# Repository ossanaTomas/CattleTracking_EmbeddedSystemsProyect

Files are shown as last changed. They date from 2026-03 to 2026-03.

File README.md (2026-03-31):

# Cattle Tracking System — Embedded Systems Project

## Table of Contents

- [Motivation](#motivation)
- [Overview](#overview)
- [Key Features](#key-features)
- [Repository Structure](#repository-structure)
- [Hardware Design](#hardware-design)
  - [Tracker Board (Collar Node)](#tracker-board-collar-node)
  - [Base Station Board](#base-station-board)
- [Firmware](#firmware)
  - [Tracker Firmware](#tracker-firmware-firmwarefirmware-tracker)
  - [Base Station Firmware](#base-station-firmware-firmwarefirmware-base-station)
- [Communication Protocol](#communication-protocol)
- [Dashboard Application](#dashboard-application-dashboard-app)
- [Technology Stack Summary](#technology-stack-summary)
- [Academic Context](#academic-context)
- [Author](#author)

---

## Motivation

My father is a farmer. Every single day he drives out to the field to walk the land, check on the animals, make sure they are healthy and in the right paddock. It is a time-consuming routine that depends entirely on being physically present.

That got me thinking: what if I could apply my knowledge as an engineering student to make his daily work easier? With a satellite tracking system he could simply pull out his phone, check an app, and know the status of every animal in real time — without leaving the house.

That question became this project. For the *Programación de Sistemas Embebidos* course I decided to build a **low-power, long-range embedded solution** that tackles exactly that problem. The result is a working prototype: custom PCBs, bare-metal firmware, a LoRa radio link, and a web dashboard, all built from scratch.

The system is still a prototype and has room to grow in several areas, but it is **fully functional** — and with a reasonable amount of additional development it could be deployed in a real field environment without any fundamental obstacles.

---

## Overview

An end-to-end **IoT solution for GPS-based livestock tracking** built entirely from scratch — custom PCBs, embedded firmware, and a web dashboard included.

The goal was to design a **low-power, long-range** monitoring system that can be attached to cattle collars. Each collar (tracker node) periodically collects GPS coordinates and body temperature, and transmits this data wirelessly to a fixed base station using **LoRa radio modules**. The base station forwards all received data to a PC, where a web application stores and visualizes it in real time.

```
┌─────────────────────────────────────────────────────────────────┐
│                         FIELD                                   │
│                                                                 │
│  ┌──────────────┐       LoRa        ┌──────────────────────┐   │
│  │   Tracker    │ ────────────────► │    Base Station      │   │
│  │  (Collar)    │ ◄──────── ACK/CFG │  (Fixed / Fencepost) │   │
│  │              │                   │                      │   │
│  │ STM32F103    │                   │ STM32F103            │   │
│  │ GPS (u-blox) │                   │ USB CDC              │   │
│  │ DS18B20 Temp │                   └──────────┬───────────┘   │
│  │ SX127x LoRa  │                              │               │
│  └──────────────┘                              │ USB Serial    │
│                                                │               │
└────────────────────────────────────────────────┼───────────────┘
                                                 │
                                    ┌────────────▼──────────────┐
                                    │     Dashboard App (PC)    │
                                    │   FastAPI + SQLite + Web  │
                                    └───────────────────────────┘
```

---

<p align="center">
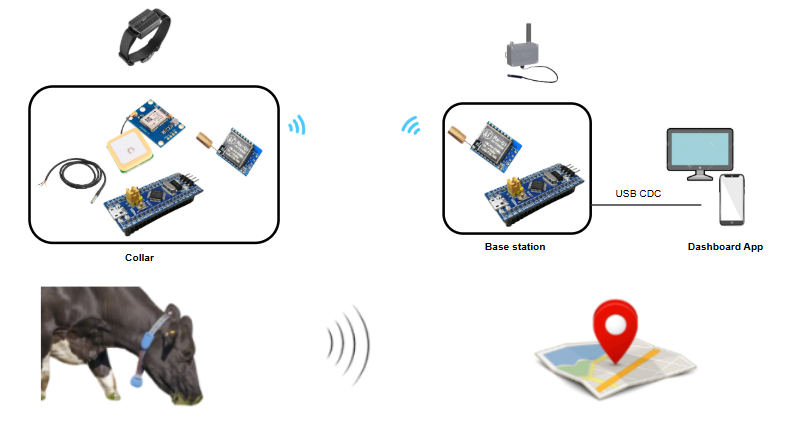
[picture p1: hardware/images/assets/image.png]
sistem
  
</p>

## Key Features

- **GPS tracking** — latitude, longitude, satellite count and heading, with 0.0001° precision
- **Temperature monitoring** — DS18B20 sensor with 0.001 °C resolution
- **Battery voltage monitoring** — reported in millivolts
- **LoRa radio link** — long-range, low-power wireless communication (SX127x modules)
- **Two operating modes** — Continuous (every 30 s) and Low-Power (configurable interval with GPS pre-warming)
- **Reliable delivery (Stop-and-Wait ARQ)** — every DATA frame is acknowledged; unacknowledged frames are retried
- **Remote reconfiguration** — the base station can push configuration changes (mode, interval, GPS timers) via piggybacked ACK frames
- **Persistent configuration** — node settings survive power cycles (stored in Flash)
- **CRC16-CCITT integrity checks** — every frame is verified on both ends
- **Comprehensive error reporting** — 16-bit error mask covers GPS fix failures, sensor errors, battery alerts, and radio issues
- **Web dashboard** — real-time visualization of all received telemetry; debug view with raw frame inspection

---

## Repository Structure

```
EmbeddedSystemProyect/
├── firmware/
│   ├── firmware-tracker/          # STM32 firmware for the collar node
│   │   ├── Core/
│   │   │   ├── Inc/               # Header files
│   │   │   └── Src/               # C source files
│   │   ├── Drivers/               # STM32 HAL + CMSIS
│   │   └── EmbeddedSystemProyect.ioc
│   └── firmware-base-station/     # STM32 firmware for the base station
│       ├── Core/
│       │   ├── Inc/
│       │   └── Src/
│       ├── Drivers/
│       ├── Middlewares/           # USB Device stack (CDC)
│       └── Base_station.ioc
├── hardware/
│   ├── kicad/
│   │   ├── tracker-board/         # KiCad schematic + PCB for the collar
│   │   └── base-station-board/    # KiCad schematic + PCB for the base station
│   └── images/
│       ├── tracker-boad/          # Schematics, renders, and photos — tracker
│       └── base-station-board/    # Schematics, renders, and photos — base station
└── dashboard-app/                 # Python FastAPI web application
    ├── app/
    │   ├── api/                   # REST endpoints
    │   ├── db/                    # SQLAlchemy models + SQLite session
    │   ├── proto/                 # Frame parser + CRC16
    │   ├── serial/                # Serial port reader (USB CDC)
    │   └── web/                   # Jinja2 templates (dashboard, debug, mode)
    └── requirements.txt
```

---

## Hardware Design

Both boards were designed from scratch in **KiCad**, manufactured, hand-assembled, and tested.

### Tracker Board (Collar Node)

The tracker is a compact, battery-powered board designed to be mounted on a livestock collar. It integrates the microcontroller, LoRa module footprint, GPS connector, temperature sensor interface, and power management in a single PCB.

**Schematic**

<p align="center">
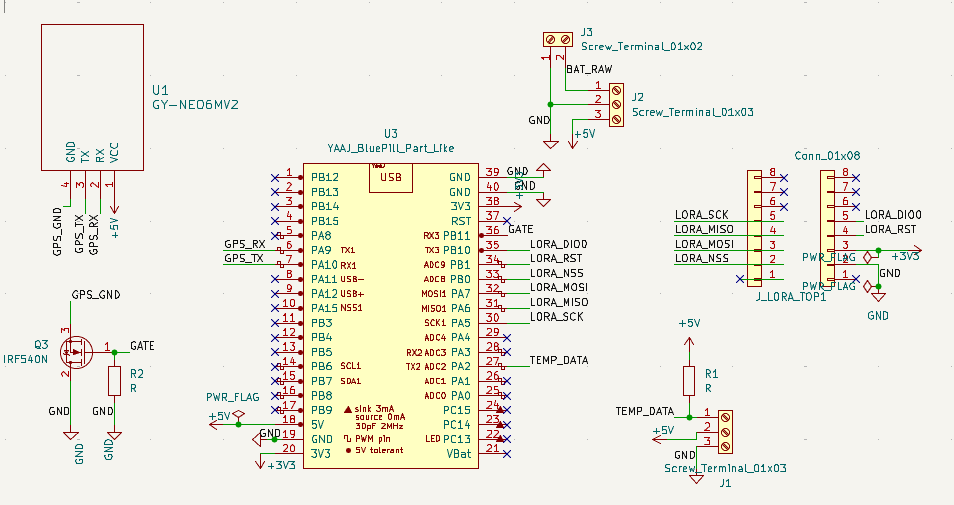
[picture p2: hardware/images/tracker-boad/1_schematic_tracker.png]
Tracker Schematic
  
</p>

**PCB Layout**

<p align="center">
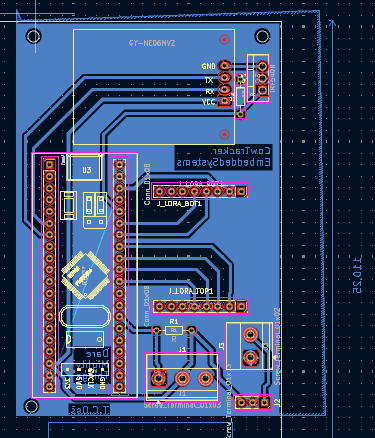
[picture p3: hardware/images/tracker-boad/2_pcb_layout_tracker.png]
Tracker PCB Layout
  
</p>

**3D Renders**

| Front | Back |
|---|---|
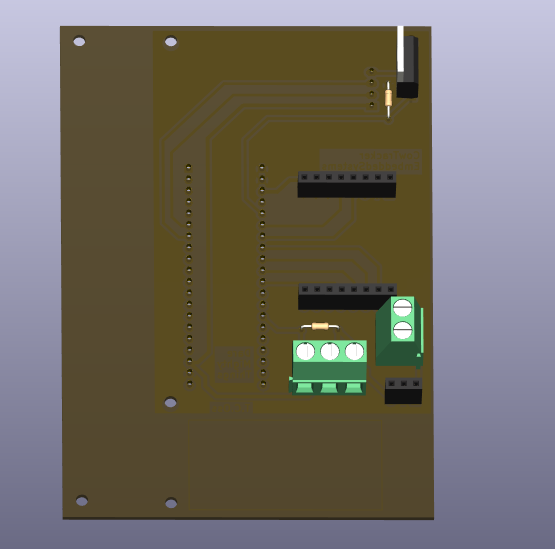
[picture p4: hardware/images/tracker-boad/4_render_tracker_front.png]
Tracker Front Render
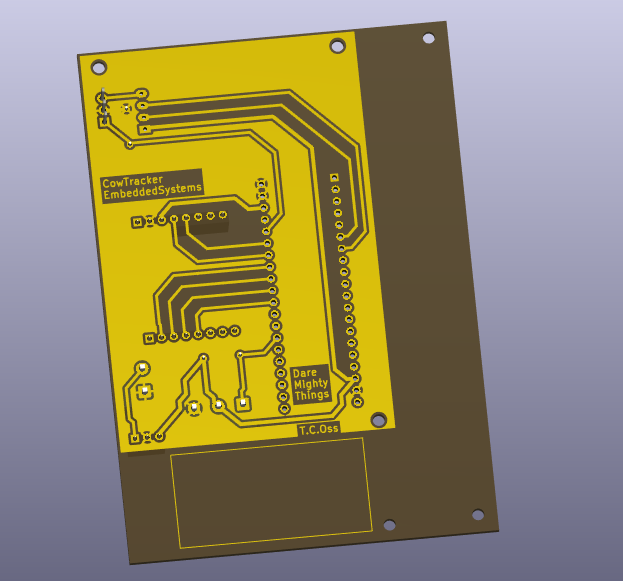
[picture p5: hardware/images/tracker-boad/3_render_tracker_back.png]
Tracker Back Render
|  |  |

**Fabrication & Assembly**

<p align="center">
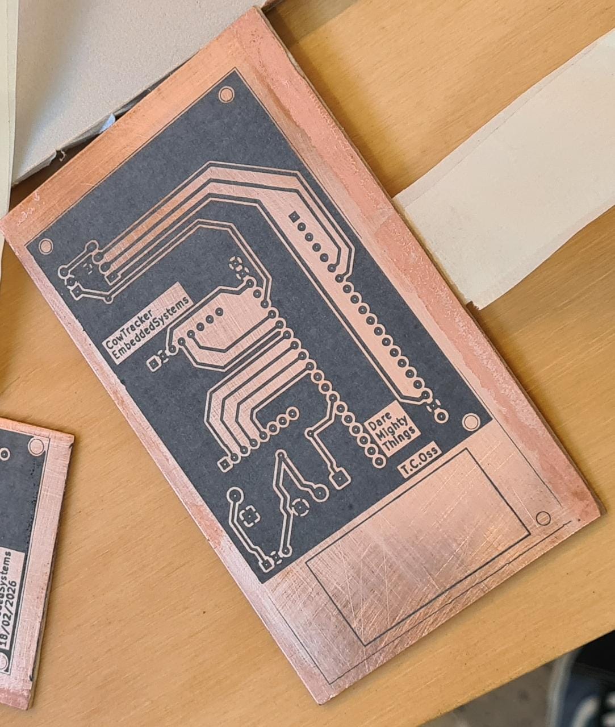
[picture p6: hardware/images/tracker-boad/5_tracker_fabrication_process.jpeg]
Tracker Fabrication Process
  
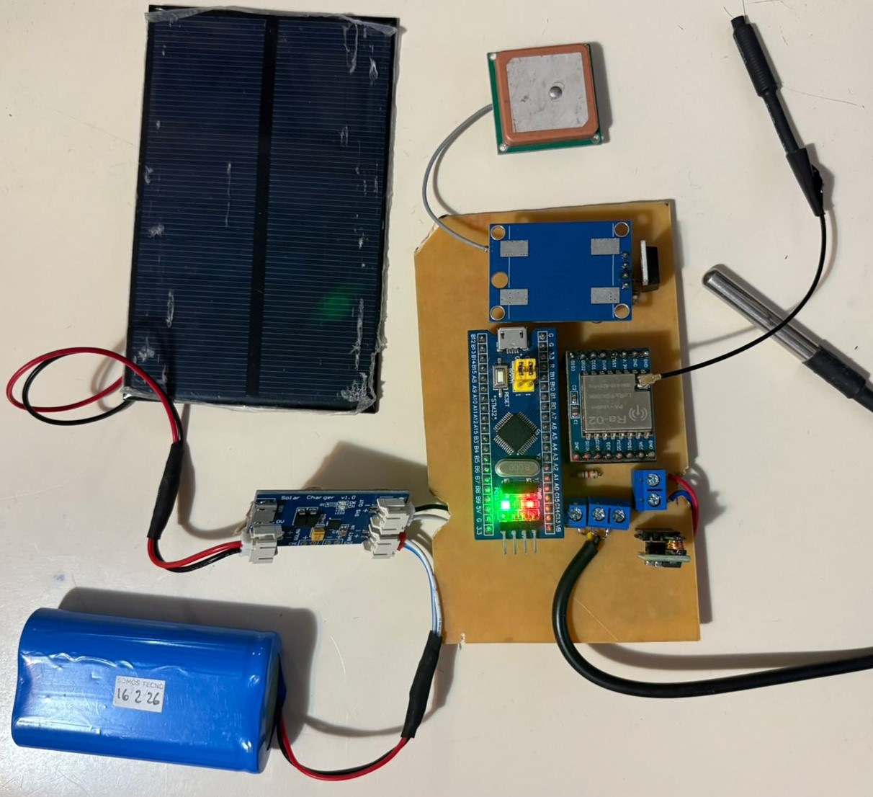
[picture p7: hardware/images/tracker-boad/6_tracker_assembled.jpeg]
Tracker Assembled
  
</p>

**Mounted on Collar**

<p align="center">
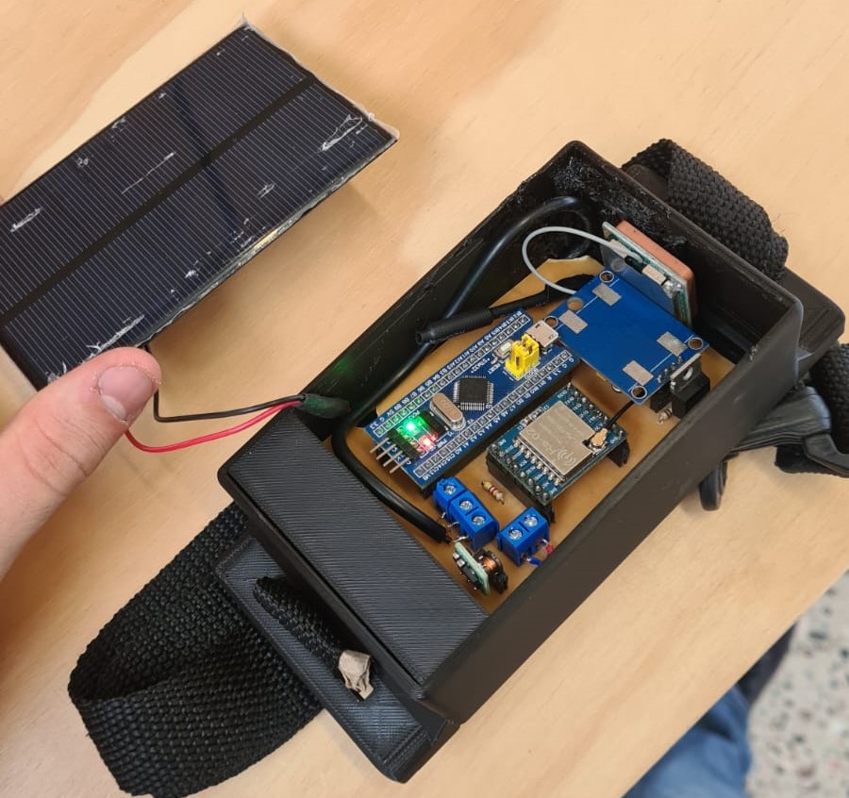
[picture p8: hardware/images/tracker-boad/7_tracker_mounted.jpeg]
Tracker Mounted 1
  
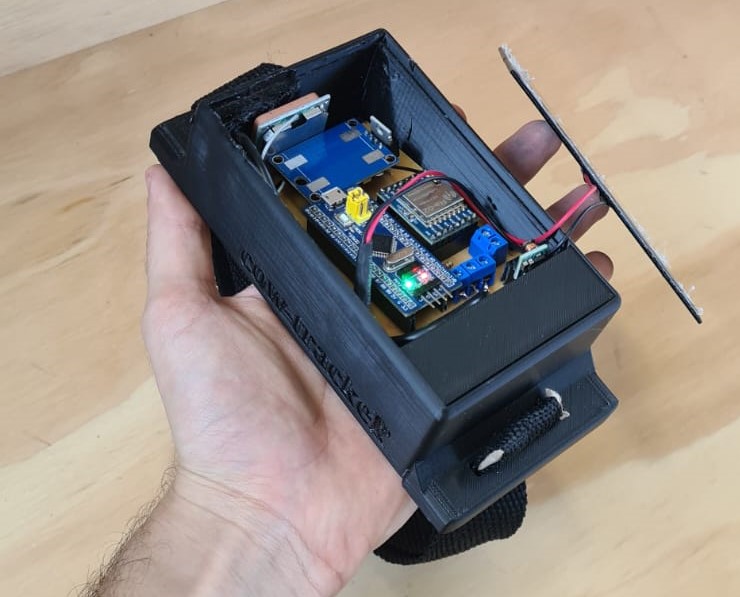
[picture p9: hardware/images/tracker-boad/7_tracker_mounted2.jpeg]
Tracker Mounted 2
  
</p>

<p align="center">
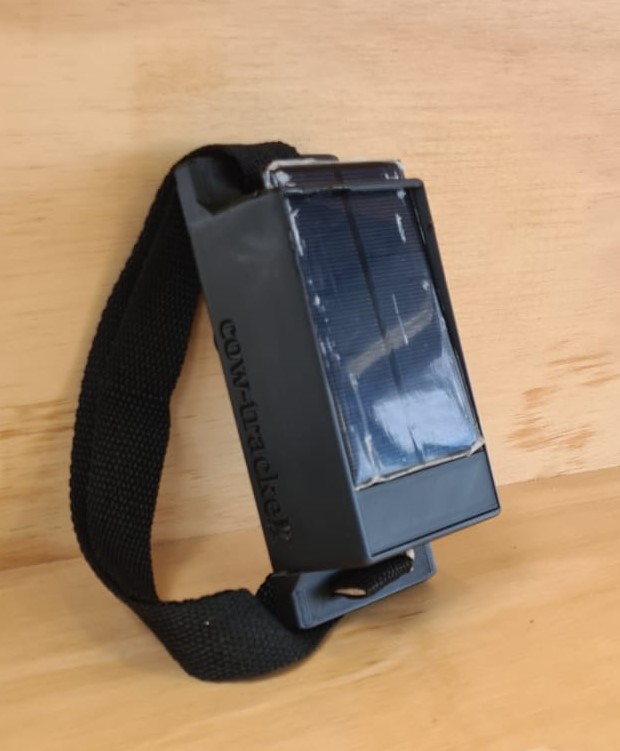
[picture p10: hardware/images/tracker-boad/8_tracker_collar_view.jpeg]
Collar View 1
  
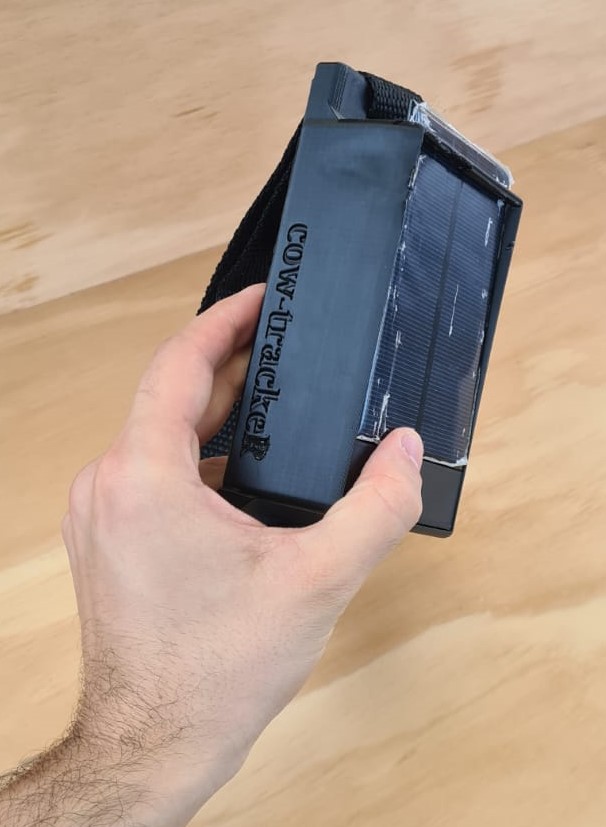
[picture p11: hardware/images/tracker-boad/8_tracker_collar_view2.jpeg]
Collar View 2
  
</p>

---

### Base Station Board

The base station is a fixed-installation board. It receives LoRa frames from all trackers in range and forwards the raw data to a PC over USB (CDC virtual serial port).

**Schematic**

<p align="center">
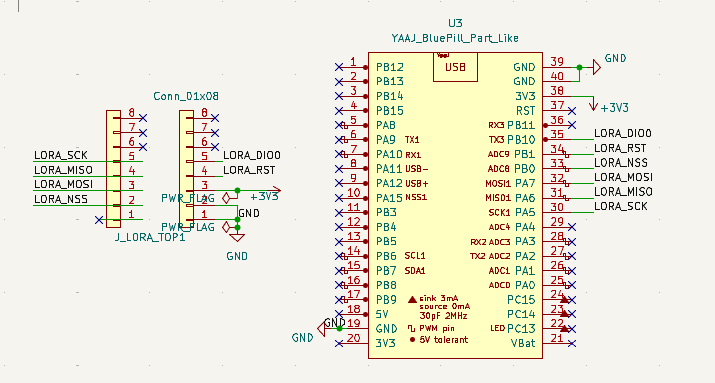
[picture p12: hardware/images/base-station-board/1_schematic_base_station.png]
Base Station Schematic
  
</p>

**PCB Layout**

<p align="center">
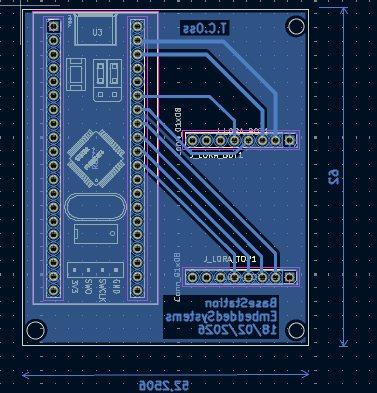
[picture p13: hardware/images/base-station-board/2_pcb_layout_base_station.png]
Base Station PCB Layout
  
</p>

**3D Renders**

<p align="center">
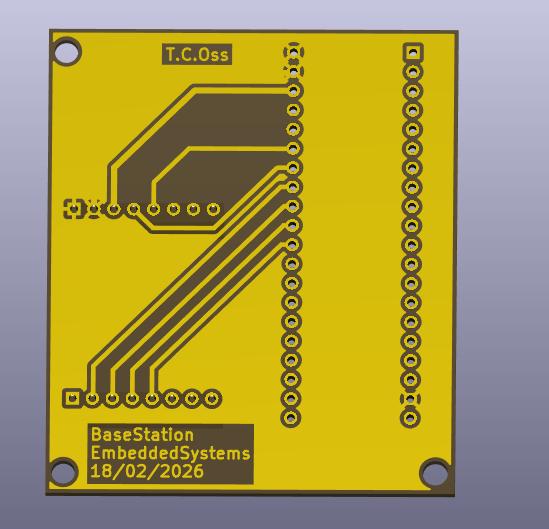
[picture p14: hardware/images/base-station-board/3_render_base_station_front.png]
Base Station Front Render
  
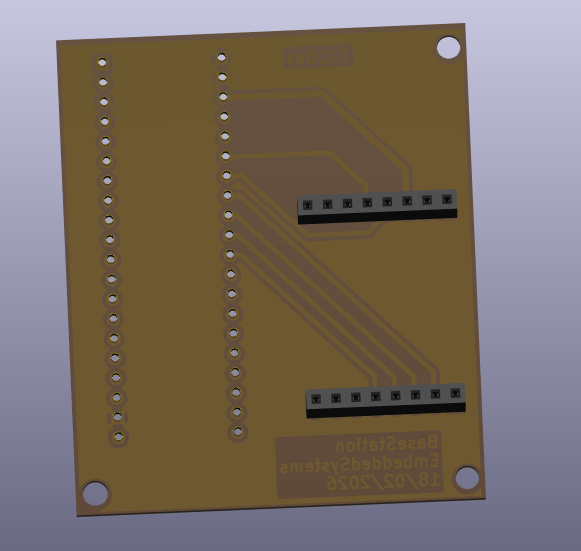
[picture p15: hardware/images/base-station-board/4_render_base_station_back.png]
Base Station Back Render
  
</p>

**Fabrication & Result**

<p align="center">
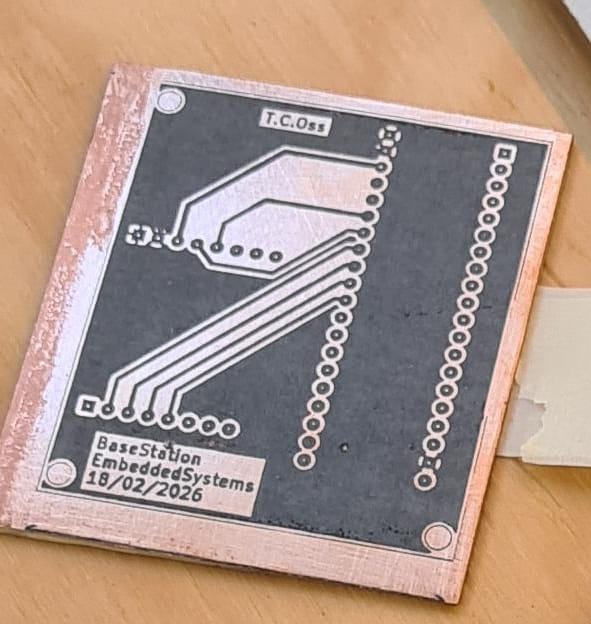
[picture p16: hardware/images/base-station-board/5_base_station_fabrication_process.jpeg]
Base Station Fabrication
  
</p>

<p align="center">
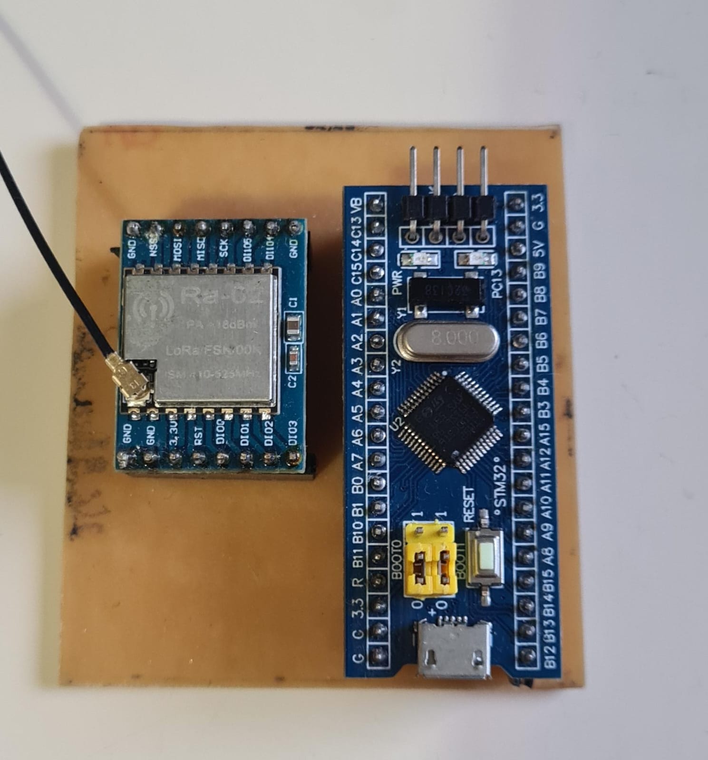
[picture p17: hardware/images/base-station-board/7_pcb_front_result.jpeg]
Base Station PCB Front
  
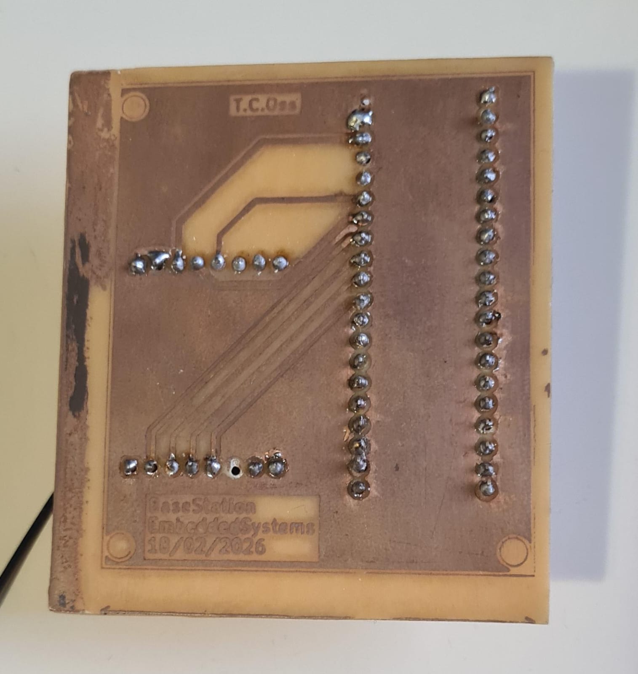
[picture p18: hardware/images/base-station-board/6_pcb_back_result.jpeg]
Base Station PCB Back
  
</p>
---

## Firmware

Both firmware projects target the **STM32F103C8T6** (ARM Cortex-M3, 64 KB Flash, 20 KB RAM) and were developed using **STM32CubeIDE**. 

### Tracker Firmware (`firmware/firmware-tracker`)

The tracker firmware follows a clean layered architecture:

```
┌─────────────────────────────────────────┐
│          Application Layer              │  node.c — NodeSimple_Task()
│  (mode management, data collection,     │  node_cfg.c — Flash persistence
│   TX scheduling, RX window)             │
├─────────────────────────────────────────┤
│           Service Layer                 │  gps.c — NMEA / UBX parser
│  (sensor acquisition, GPS management,  │  service_temp.c — DS18B20 service
│   temperature, battery)                 │
├─────────────────────────────────────────┤
│          Protocol Layer                 │  frame.c — pack/unpack frames
│  (framing, CRC16, ARQ link layer)       │  crc16_ccitt.c
│                                         │  node_link.c — Stop-and-Wait ARQ
├─────────────────────────────────────────┤
│       Hardware Abstraction Layer        │  LoRa.c — SX127x SPI driver
│  (LoRa radio, OneWire, UART, SPI, GPIO) │  ds18b20.c + onewire_uart.c
│                                         │  STM32 HAL (SPI1, USART1/2, GPIO)
└─────────────────────────────────────────┘
```

#### Peripheral Mapping

| Peripheral | Pins | Purpose |
|---|---|---|
| SPI1 | PA5 / PA6 / PA7 | LoRa SX127x data bus (SCK / MISO / MOSI) |
| GPIO | PB0 / PB1 / PB10 | LoRa NSS (chip-select) / RST / DIO0 (IRQ) |
| USART1 | PA9 / PA10 | GPS UART @ 9600 baud (NMEA + UBX) |
| GPIO | PB11 | GPS power enable |
| USART2 | PA2 (half-duplex) | OneWire bus for DS18B20 @ 115200 baud |
| GPIO | PC13 | Status LED |
| SWD | PA13 / PA14 | Programming interface |

#### Operating Modes

**Continuous Mode (`NODE_MODE_CONTINUOUS`)**
Transmits a DATA frame every 30 seconds with the GPS running continuously. Prioritizes update frequency over power consumption — suitable for short-duration operations or testing.

**Low-Power Mode (`NODE_MODE_LOW_POWER`)**
Designed for multi-day battery life. The GPS is kept off between transmissions. Before each scheduled TX, the GPS is powered on for a configurable pre-warm period (`gps_prewarm_s`) to start acquiring satellites. An additional wait (`gps_extra_wait_s`) is allowed to obtain a valid fix. After transmission, the GPS is powered down again.

Both modes and their timing parameters are configurable and persist across reboots in **Flash memory** (last 1 KB page at address `0x0800F800`).

#### Reliable Delivery (Stop-and-Wait ARQ)

After each DATA frame is transmitted, the node opens a **receive window** waiting for an ACK from the base station. If no ACK is received within the timeout, the frame is retried up to `n_retries` times. The ACK frame can optionally carry a `CFG` payload, allowing the base station to push updated configuration to the node without a separate control channel.

#### Initialization Sequence

```
HAL_Init() → SystemClock_Config()
  → MX_GPIO_Init()
  → MX_USART1_UART_Init()  (GPS @ 9600 baud)
  → MX_USART2_UART_Init()  (OneWire / DS18B20 @ 115200 baud)
  → MX_SPI1_Init()         (LoRa @ 8 Mbit/s)
  → GPS_Init()
  → TempService_Init(&huart2, DS18B20_RES_10BIT)
  → LoRa_init()            (retried up to 50 times)
  → NodeSimple_Init(lora, node_id=1, net_id=0x27)
  → while(1) NodeSimple_Task()
```

---

### Base Station Firmware (`firmware/firmware-base-station`)

The base station is simpler by design. Its responsibilities are:

1. Continuously listen on the LoRa channel for incoming DATA frames
2. Send an ACK frame back to the transmitting node (optionally with a CFG payload)
3. Forward received frames to the PC over **USB CDC** (virtual serial port)
4. Accept commands from the PC (`pc_cmd.c`) to push configuration changes to specific nodes

It exposes a USB CDC virtual COM port to the host PC, over which raw received frames (prefixed with RSSI) are streamed. The dashboard app reads this serial stream.

---

## Communication Protocol

All LoRa transmissions use a custom binary framing protocol with CRC integrity verification.

### Frame Structure

```
 ┌──────────────────────────┬────────────────────┬───────────────┐
 │       HEADER (8 bytes)   │  PAYLOAD (variable) │  CRC16 (2 B)  │
 └──────────────────────────┴────────────────────┴───────────────┘

Header fields:
  [0] VER    — Protocol version (0x01)
  [1] NET    — Network ID (0x27 by default)
  [2] TYPE   — Message type
  [3] SRC    — Source node address
  [4] DST    — Destination address (0xFF = broadcast)
  [5] SEQ    — Sequence number (0–255, wraps around)
  [6] FLAGS  — Validity bits (GPS_VALID | TEMP_VALID | BATT_VALID)
  [7] PLEN   — Payload length in bytes
```

### Message Types

| Type | Code | Direction | Description |
|---|---|---|---|
| DATA | `0x10` | Tracker → Base | Sensor telemetry payload |
| ERR  | `0x11` | Tracker → Base | Error notification with text |
| ACK  | `0x30` | Base → Tracker | Acknowledgment (may carry CFG) |
| CFG  | `0x20` | Base → Tracker | Remote configuration update |

### DATA Payload (27 bytes)

```c
typedef struct {
    uint32_t t_ms;            // Node uptime in milliseconds
    uint32_t utc_raw_x1e3;    // UTC time from GPS (x1000)
    int32_t  lat_raw_x1e4;    // Latitude  ddmm.mmmm x 10000 (negative = S)
    int32_t  lon_raw_x1e4;    // Longitude dddmm.mmmm x 10000 (negative = W)
    uint8_t  sats;            // Number of satellites in view
    uint16_t course_cdeg;     // Heading in centidegrees (degrees x 100)
    int32_t  temp_mC;         // Temperature in milli-Celsius
    uint16_t batt_mV;         // Battery voltage in millivolts
    uint16_t err_mask;        // 16-bit error flags
} proto_data_t;
```

### Error Mask Bits

| Bit | Meaning |
|-----|---|
| 0 | GPS no fix |
| 1 | GPS parse error |
| 2 | GPS configuration error |
| 3 | Temperature sensor read failure |
| 4 | Temperature sensor not detected |
| 5 | Battery voltage critical |
| 6 | LoRa TX failure |
| 7 | ACK timeout (max retries exceeded) |
| 8 | CRC verification failure |

### CFG Payload (6 bytes)

The base station can remotely reconfigure any tracker by piggybacking a CFG payload onto the ACK response:

```c
typedef struct {
    uint8_t  cfg_seq;        // Sequence number (idempotent updates)
    uint8_t  mode;           // 0 = CONTINUOUS, 1 = LOW_POWER
    uint16_t interval_s;     // TX interval in seconds (Low-Power mode)
    uint8_t  gps_prewarm_s;  // Seconds to power GPS before TX
    uint8_t  gps_extra_s;    // Extra seconds to wait for GPS fix
} proto_cfg_t;
```

---

## Dashboard Application (`dashboard-app`)

A Python web application that receives telemetry from the base station and exposes it through a browser-based interface.

<p align="center">
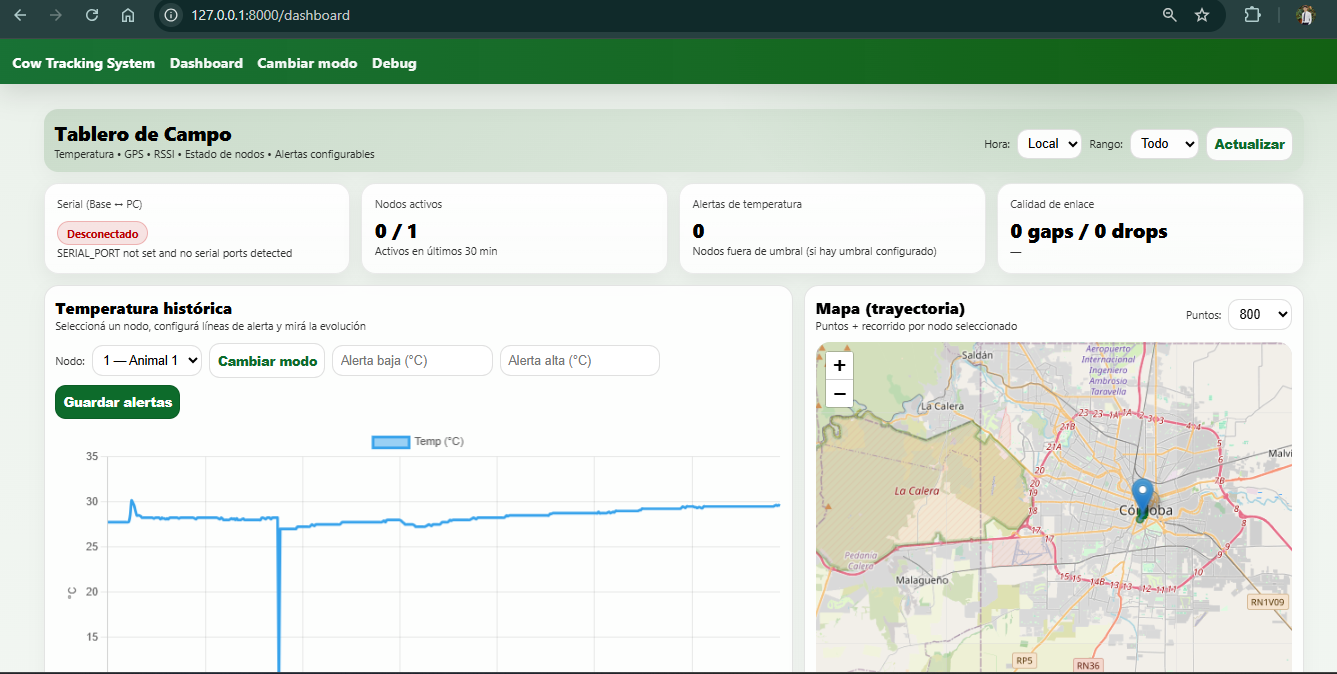
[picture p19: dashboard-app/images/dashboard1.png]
  
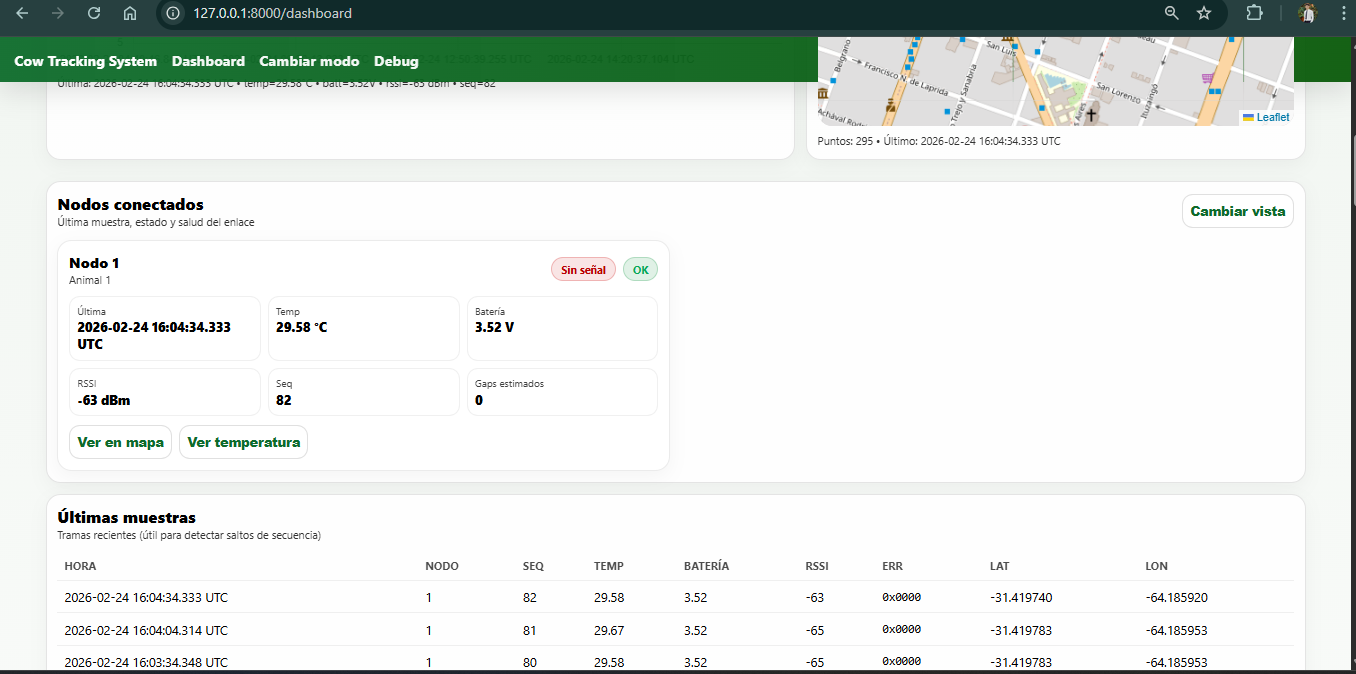
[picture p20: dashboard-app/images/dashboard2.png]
  
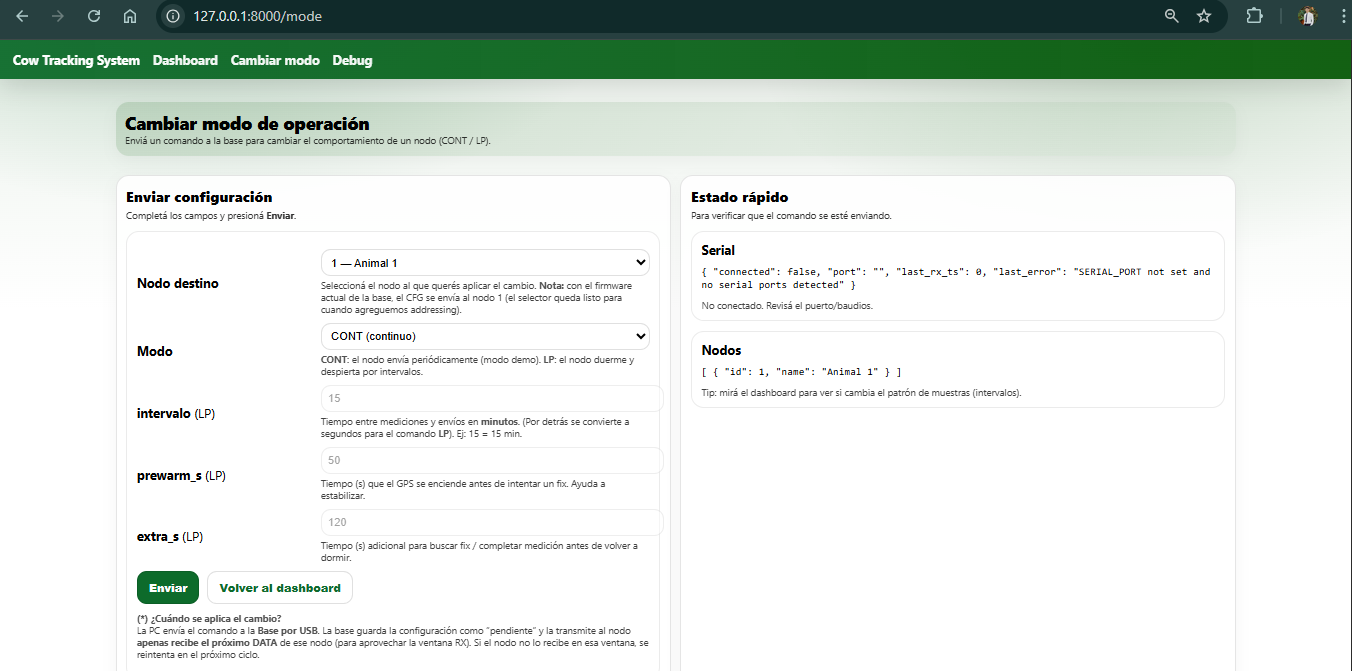
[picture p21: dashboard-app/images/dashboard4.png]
  
</p>

### Architecture

```
USB Serial (base station)
        │
        ▼
  SerialManager        ← background thread, reads raw frames
        │
        ▼
  Frame Parser         ← unpack header + payload, verify CRC16
        │
        ▼
  SQLite Database      ← stores Node and Frame records (SQLAlchemy)
        │
        ├──► REST API  (/api/...)   ← JSON endpoints
        └──► Web UI    (/dashboard, /debug, /mode)
```

### Components

| Module | Role |
|---|---|
| `serial/serial_manager.py` | Reads raw bytes from USB CDC serial port in a background thread |
| `proto/frame.py` | Unpacks binary frames, parses DATA payload, converts raw coordinates to decimal degrees |
| `proto/crc16.py` | CRC16-CCITT verification |
| `db/models.py` | `Node` and `Frame` SQLAlchemy ORM models |
| `api/routes.py` | REST endpoints exposing stored telemetry as JSON |
| `web/templates/dashboard.html` | Main live telemetry dashboard |
| `web/templates/debug.html` | Raw frame inspection view |
| `web/templates/mode.html` | Push configuration changes to nodes |

### Frame Deduplication

The tracker can transmit the same frame twice as a redundancy measure. The dashboard app silently deduplicates frames with the same `(node_id, seq)` arriving within a 5-second window before storing them in the database. It also tracks sequence number gaps to detect lost packets.

### Tech Stack

| Library | Version | Purpose |
|---|---|---|
| FastAPI | 0.115.0 | Web framework + REST API |
| Uvicorn | 0.30.6 | ASGI server |
| SQLAlchemy | 2.0.32 | ORM + SQLite session management |
| Pydantic | 2.8.2 | Data validation and schemas |
| pyserial | 3.5 | USB CDC serial communication |
| Jinja2 | 3.1.4 | HTML templating |

### Running the Dashboard

```bash
cd dashboard-app
pip install -r requirements.txt
uvicorn app.main:app --reload
```

Then open `http://localhost:8000/dashboard` in a browser.

The app auto-detects the base station's COM port. If multiple serial ports are available, it can be specified via the `SERIAL_PORT` environment variable:

```bash
SERIAL_PORT=COM3 uvicorn app.main:app --reload
```

---

## Technology Stack Summary

| Layer | Technology |
|---|---|
| Microcontroller | STM32F103C8T6 (ARM Cortex-M3 @ 16 MHz, 64 KB Flash, 20 KB RAM) |
| IDE / Toolchain | STM32CubeIDE + GNU ARM Embedded (arm-none-eabi-gcc) |
| HAL | STM32 HAL (SPI, UART, GPIO, USB Device) |
| Radio | LoRa SX127x (SPI @ 8 Mbit/s) |
| GPS | u-blox NEO6Mv2  (NMEA + UBX, UART @ 9600 baud) |
| Temperature | DS18B20 via OneWire-over-UART (UART @ 115200 baud, half-duplex) |
| PCB Design | KiCad |
| Backend | Python 3, FastAPI, SQLAlchemy, SQLite |
| Frontend |(server-rendered HTML) |

---

## Academic Context

This project was developed as the final deliverable for the **Programación de Sistemas Embebidos** course at **Universidad Católica de Córdoba (UCC)**, Faculty of Engineering. The course focuses on bare-metal and HAL-based programming for ARM Cortex-M microcontrollers, primarily using ST boards (STM32 Blue Pill, STM32 Discovery).

The project was structured as two incremental deliveries:

- **Partial 1** — Initial hardware design and basic sensor + LoRa communication prototype
- **Partial 2** — Full system integration: reliable delivery, operating modes, configuration persistence, and dashboard application

The complete system was presented and demonstrated working as the final exam.

---

## Author

👨‍💻 **Tomás Ossana**

Computer Engineering student — Universidad Católica de Córdoba (UCC), Argentina.

This project was built for educational purposes and puts into practice fundamental concepts acquired throughout the course and the degree, spanning both software and hardware development. 

It was a challenging, integrative, and genuinely enjoyable project from start to finish. Every module integration came with its own set of obstacles, and solving them was just as satisfying as watching the complete system work end to end. I leaned and enjoy a lot during this subjet and that's the most important of all!! 

---
*Universidad Católica de Córdoba — Ingeniería en Computación — 2025*

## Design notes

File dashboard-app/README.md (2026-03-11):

# AgroOS / Cattle Tracking Backend (FastAPI + SQLite)

This backend:
- Reads LoRa frames forwarded over USB CDC (COM port) from the Base Station.
- Decodes frames (DATA type 0x10) and stores them in SQLite.
- Exposes REST APIs for latest, history, tracks.
- Provides two UIs:
  - `/debug` (raw frames + decoded fields + errors)
  - `/dashboard` ("Field dashboard": KPIs, temp chart + alert lines, map with points+track, latest samples)

## Run

```bash
python -m venv .venv
# Windows:
#   .venv\Scripts\activate
# Linux/Mac:
#   source .venv/bin/activate
pip install -r requirements.txt

# Set your serial port, e.g. COM3 on Windows, /dev/ttyACM0 on Linux
set SERIAL_PORT=COM3
set SERIAL_BAUD=115200
set DB_PATH=agroos.db

uvicorn app.main:app --host 127.0.0.0 --port 8080
```

Open:
- http://localhost:8080/dashboard
- http://localhost:8080/debug
- http://localhost:8080/mode
- http://localhost:8080/docs

## Notes (important for "it must work")

- **No more "node 0"**: corrupted frames (CRC/length mismatch) are ignored so the UI doesn't get polluted.
  The dashboard still shows counters (drops + estimated seq gaps).
- **Time handling**: the UI uses the server receive timestamp as the source of truth and can display it as
  **Local** or **UTC**.
- **Alert lines**: you can store per-node low/high temperature thresholds. They are drawn as horizontal lines
  on the chart and also used to highlight points on the map.

## Serial input format

Supports Base Station output like:
- `DATA? type=0x10 src=1 dst=0 seq=216 flags=0x10 plen=23 rssi=-49`
- `RX 33B: 01 23 10 01 00 D8 10 17 ...`
Only the `RX ...` line is required; RSSI is taken from the optional DATA line when available.

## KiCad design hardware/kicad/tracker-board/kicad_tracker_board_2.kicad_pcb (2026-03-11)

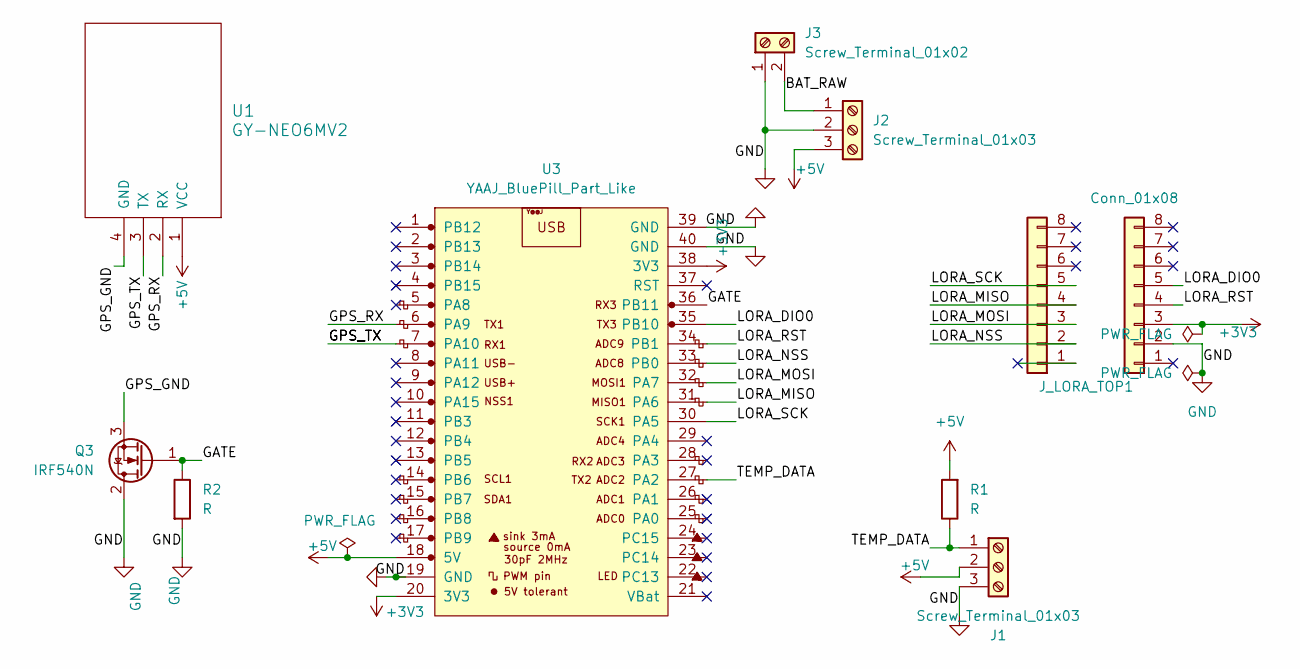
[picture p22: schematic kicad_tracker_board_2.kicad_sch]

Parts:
J1: Screw_Terminal_01x03; TerminalBlock_Phoenix_MKDS-1,5-3-5.08_1x03_P5.08mm_Horizont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
J2: Screw_Terminal_01x03; PinSocket_1x03_P2.54mm_Vertical
J3: Screw_Terminal_01x02; TerminalBlock_Phoenix_MKDS-1,5-2_1x02_P5.00mm_Horizontal
J_LORA_BOT1: Conn_01x08; PinSocket_1x08_P2.54mm_Vertical
J_LORA_TOP1: Conn_01x08; PinSocket_1x08_P2.54mm_Vertical
Q3: IRF540N; TO-220-3_Vertical
R1, R2: R; R_Axial_DIN0204_L3.6mm_D1.6mm_P7.62mm_Horizontal
U1: GY-NEO6MV2
U3: YAAJ_BluePill_Part_Like; YAAJ_BluePill_1

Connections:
+3V3: J_LORA_BOT1.3, U3.20 (3V3), U3.38 (3V3)
+5V: J1.2, J2.3, R1.2, U1.1 (VCC), U3.18 (5V)
/BAT_RAW: J2.1, J3.2
/GATE: Q3.1 (G), R2.1, U3.36 (PB11)
/GPS_GND: Q3.3 (S), U1.4 (GND)
/GPS_RX: U1.2 (RX), U3.6 (PA9)
/GPS_TX: U1.3 (TX), U3.7 (PA10)
/LORA_DIO0: J_LORA_BOT1.5, U3.35 (PB10)
/LORA_MISO: J_LORA_TOP1.4, U3.31 (PA6)
/LORA_MOSI: J_LORA_TOP1.3, U3.32 (PA7)
/LORA_NSS: J_LORA_TOP1.2, U3.33 (PB0)
/LORA_RST: J_LORA_BOT1.4, U3.34 (PB1)
/LORA_SCK: J_LORA_TOP1.5, U3.30 (PA5)
/TEMP_DATA: J1.1, R1.1, U3.27 (PA2)
GND: J1.3, J2.2, J3.1, J_LORA_BOT1.2, Q3.2 (D), R2.2, U3.19 (GND), U3.39 (GND), U3.40 (GND)

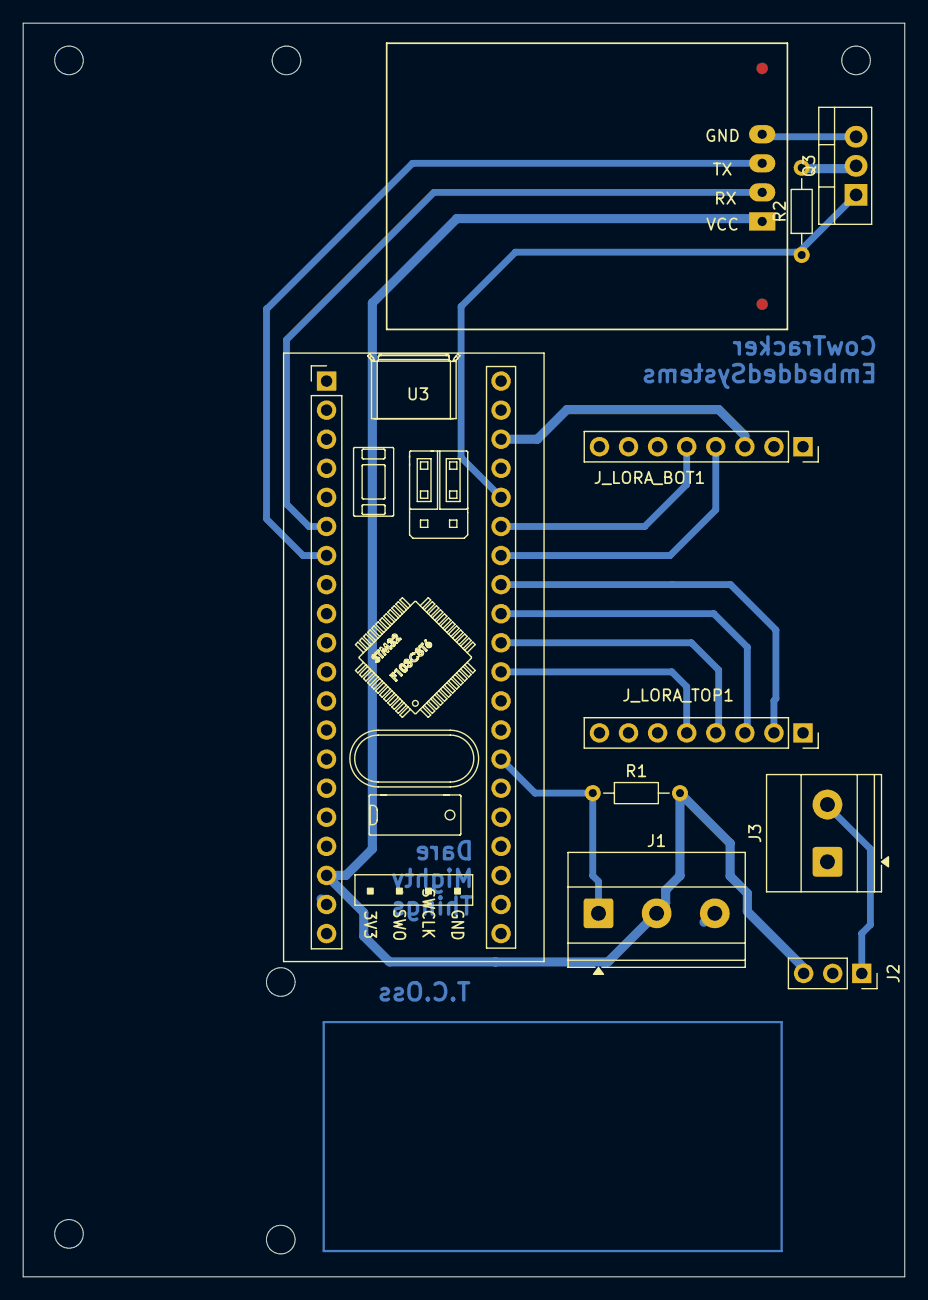
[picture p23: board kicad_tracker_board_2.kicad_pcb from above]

Board: 2 copper layers, 77.0 x 109.5 mm, 10 parts (0 on the bottom side), 15 nets.

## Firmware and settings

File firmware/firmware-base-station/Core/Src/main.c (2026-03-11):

	/* USER CODE BEGIN Header */
/**
  ******************************************************************************
  * @file           : main.c
  * @brief          : Main program body
  ******************************************************************************
  * @attention
  *
  * Copyright (c) 2026 STMicroelectronics.
  * All rights reserved.
  *
  * This software is licensed under terms that can be found in the LICENSE file
  * in the root directory of this software component.
  * If no LICENSE file comes with this software, it is provided AS-IS.
  *
  ******************************************************************************
  */
/* USER CODE END Header */
/* Includes ------------------------------------------------------------------*/
#include "main.h"
#include "spi.h"
#include "usb_device.h"
#include "gpio.h"

/* USER CODE BEGIN Includes */
#include "usbd_cdc_if.h"
#include <string.h>
#include <stdio.h>
#include "LoRa.h"
#include "base_simple.h"
/* USER CODE END Includes */


/* USER CODE BEGIN PV */
extern volatile uint8_t  g_usb_rx_ready;
extern volatile uint32_t g_usb_rx_len;
volatile uint8_t g_rx_len = 0;
extern uint8_t g_usb_rx_buf[64];

static uint8_t CDC_Transmit_Blocking(uint8_t *buf, uint16_t len, uint32_t timeout_ms)
{
    uint32_t t0 = HAL_GetTick();
    while (CDC_Transmit_FS(buf, len) == USBD_BUSY) {
        if ((HAL_GetTick() - t0) >= timeout_ms) return USBD_BUSY;
        HAL_Delay(1);
    }
    return USBD_OK;
}


/* USER CODE END PV */

void SystemClock_Config(void);
/* USER CODE BEGIN 0 */
#include <inttypes.h>

static inline uint16_t get_u16_le(const uint8_t *p) {
    return (uint16_t)p[0] | ((uint16_t)p[1] << 8);
}
static inline uint32_t get_u32_le(const uint8_t *p) {
    return (uint32_t)p[0] |
           ((uint32_t)p[1] << 8) |
           ((uint32_t)p[2] << 16) |
           ((uint32_t)p[3] << 24);
}
static inline int32_t get_i32_le(const uint8_t *p) {
    return (int32_t)get_u32_le(p);
}

// imprime v como entero con "frac_digits" decimales, sin float.
static void fmt_i32_scaled(char *out, size_t out_sz, int32_t v, uint32_t frac_digits)
{
    uint32_t scale = 1;
    for (uint32_t i = 0; i < frac_digits; i++) scale *= 10;

    int32_t ip = v / (int32_t)scale;
    int32_t rem = v % (int32_t)scale;
    uint32_t fp = (rem < 0) ? (uint32_t)(-rem) : (uint32_t)rem;

    // %0*u imprime con ceros a la izquierda (ancho = frac_digits)
    snprintf(out, out_sz, "%" PRId32 ".%0*" PRIu32, ip, (int)frac_digits, fp);
}

static void usb_print_frame_decoded(const uint8_t *fr, uint8_t len)
{
    // esperamos: hdr(8) + plen(23) + crc(2) = 33 para DATA
    if (len < 8) {
        const char *m = "Frame corto (<8)\r\n";
        CDC_Transmit_Blocking((uint8_t*)m, (uint16_t)strlen(m), 50);
        return;
    }

    uint8_t ver   = fr[0];
    uint8_t net   = fr[1];
    uint8_t type  = fr[2];
    uint8_t src   = fr[3];
    uint8_t dst   = fr[4];
    uint8_t seq   = fr[5];
    uint8_t flags = fr[6];
    uint8_t plen  = fr[7];

    uint16_t expected = (uint16_t)(8 + plen + 2);
    if (len != expected) {
        char msg[96];
        int n = snprintf(msg, sizeof(msg),
            "Len mismatch: got=%u expected=%u (plen=%u)\r\n", len, expected, plen);
        CDC_Transmit_Blocking((uint8_t*)msg, (uint16_t)n, 50);
        return;
    }

    const uint8_t *pl = &fr[8];

    // Por ahora decodifico solo TYPE=0x10 (DATA) y PLEN=23
    if (type == 0x10 && plen == 23) {
        uint32_t t_ms    = get_u32_le(pl + 0);
        int32_t  lat_e7  = get_i32_le(pl + 4);
        int32_t  lon_e7  = get_i32_le(pl + 8);
        uint8_t  sats    = pl[12];
        uint16_t course  = get_u16_le(pl + 13);   // centi-deg (deg*100)
        int32_t  temp_mC = get_i32_le(pl + 15);   // m°C
        uint16_t batt_mV = get_u16_le(pl + 19);   // mV
        uint16_t err     = get_u16_le(pl + 21);   // mask

        char lat_s[24], lon_s[24], temp_s[24], batt_s[24], course_s[24];
        fmt_i32_scaled(lat_s,  sizeof(lat_s),  lat_e7, 7);      // e7 -> 7 decimales
        fmt_i32_scaled(lon_s,  sizeof(lon_s),  lon_e7, 7);
        fmt_i32_scaled(temp_s, sizeof(temp_s), temp_mC, 3);     // mC -> 3 decimales
        // batt mV y course cdeg: también sin float
        snprintf(batt_s, sizeof(batt_s), "%" PRIu16 ".%03" PRIu16, (uint16_t)(batt_mV/1000), (uint16_t)(batt_mV%1000));
        snprintf(course_s, sizeof(course_s), "%" PRIu16 ".%02" PRIu16, (uint16_t)(course/100), (uint16_t)(course%100));

        char msg[220];
        int n = snprintf(msg, sizeof(msg),
            "VER=%u NET=0x%02X TYPE=0x%02X SRC=%u DST=%u SEQ=%u FLAGS=0x%02X\r\n"
            "t_ms=%" PRIu32 " lat=%s lon=%s sats=%u course=%s deg temp=%s C batt=%s V err=0x%04X\r\n\r\n",
            ver, net, type, src, dst, seq, flags,
            t_ms, lat_s, lon_s, sats, course_s, temp_s, batt_s, err);

        CDC_Transmit_Blocking((uint8_t*)msg, (uint16_t)n, 50);
        return;
    }

    // fallback: si no es DATA conocido, imprimí header al menos
    {
        char msg[120];
        int n = snprintf(msg, sizeof(msg),
            "Frame: VER=%u NET=0x%02X TYPE=0x%02X SRC=%u DST=%u SEQ=%u FLAGS=0x%02X PLEN=%u\r\n",
            ver, net, type, src, dst, seq, flags, plen);
        CDC_Transmit_Blocking((uint8_t*)msg, (uint16_t)n, 50);
    }
}



LoRa myLoRa;
uint8_t FlagRecibir=0;
uint8_t RxBuffer1[120]={0};




/* USER CODE END 0 */

/**
  * @brief  The application entry point.
  * @retval int
  */
int main(void)
{

  /* MCU Configuration--------------------------------------------------------*/

  /* Reset of all peripherals, Initializes the Flash interface and the Systick. */
  HAL_Init();

  /* Configure the system clock */
  SystemClock_Config();

  /* Initialize all configured peripherals */
  MX_GPIO_Init();
  MX_SPI1_Init();
  MX_USB_DEVICE_Init();
  /* USER CODE BEGIN 2 */
	myLoRa = newLoRa();

	myLoRa.CS_port = NSS_GPIO_Port;
	myLoRa.CS_pin = NSS_Pin;
	myLoRa.reset_port = RST_GPIO_Port;
	myLoRa.reset_pin = RST_Pin;
	myLoRa.DIO0_port = DIO0_GPIO_Port;
	myLoRa.DIO0_pin = DIO0_Pin;
	myLoRa.hSPIx = &hspi1;



	 uint32_t t0 = HAL_GetTick();
	 const char hello[] = "BluePill CDC OK\r\n";


	HAL_Delay(50);

	uint8_t LoRa_stat = 0;
	for (int i = 0; i < 1000; i++) {
		if (LoRa_init(&myLoRa) == LORA_OK) {
			LoRa_stat = 1;
			break;
		}
		HAL_Delay(50);
	}

	if (LoRa_stat != 1) {
		while (1) {

		}
	}


  BaseSimple_Init(&myLoRa);

	HAL_Delay(100);









  /* USER CODE END 2 */

  /* Infinite loop */
  /* USER CODE BEGIN WHILE */
  while (1)
  {
    BaseSimple_Task();
  }
    /* USER CODE END WHILE */

}

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
/* USER CODE BEGIN 4 */

void HAL_GPIO_EXTI_Callback(uint16_t GPIO_Pin)
{
    if (GPIO_Pin == DIO0_Pin) {
    	//HAL_GPIO_TogglePin(LED_GPIO_Port, LED_Pin);
        BaseSimple_OnDIO0IRQ();

    }
}






/* USER CODE END 4 */
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


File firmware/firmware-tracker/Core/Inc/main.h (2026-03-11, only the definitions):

#define LED_Pin GPIO_PIN_13
#define LED_GPIO_Port GPIOC
#define NSS_Pin GPIO_PIN_0
#define NSS_GPIO_Port GPIOB
#define RST_Pin GPIO_PIN_1
#define RST_GPIO_Port GPIOB
#define DIO0_Pin GPIO_PIN_10
#define DIO0_GPIO_Port GPIOB
#define DIO0_EXTI_IRQn EXTI15_10_IRQn
#define GPS_ENB_Pin GPIO_PIN_11
#define GPS_ENB_GPIO_Port GPIOB

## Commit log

2026-02-10 feat(gps): support GGA and RMC parsing; UBX configurations messages; filter unused NMEA sentences
2026-02-12 feat(Termometer): library for reading temperature
2026-02-13 refactor(thermometer): update reading temperature method;
2026-02-15 Refactor(LoRa): Change init LoRa method; SPI integration
2026-02-19 feat(frame):add frame logic and post marge LoRa
2026-02-22 Feat: Add turn On-Off GPS; Add UTC time to frame
2026-03-11 refactor(frame): change protocol tranmission logic
2026-03-11 Add kicad base-station board files
    [kicad_base_station2.kicad_pcb, kicad_base_station2.kicad_sch]
2026-03-11 Add kicad tracker board files
    [kikad_tracker_board_2.kicad_pcb, kikad_tracker_board_2.kicad_sch]
2026-03-11 Add tracker and base station images; fix some filesnames
    [kicad_base_station2.kicad_pcb, kicad_base_station2.kicad_sch, kicad_tracker_board_2.kicad_pcb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]
